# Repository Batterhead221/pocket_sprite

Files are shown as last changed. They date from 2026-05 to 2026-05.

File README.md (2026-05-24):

# POCKET_SPRITE

<p align="center">
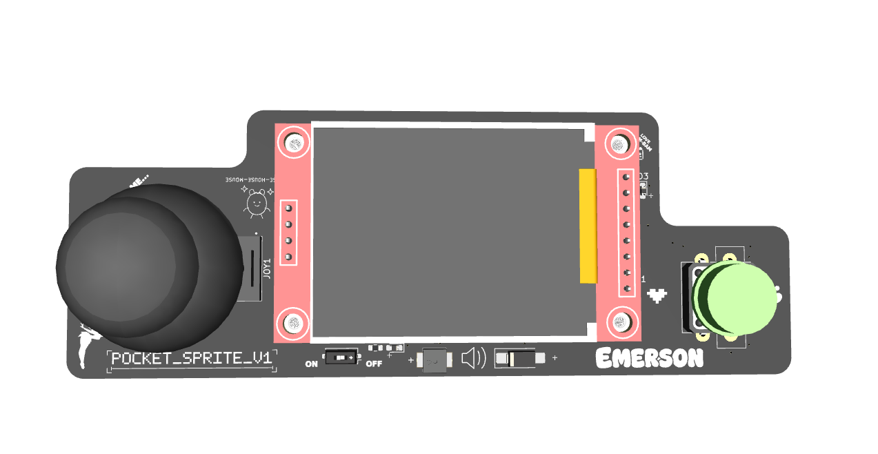
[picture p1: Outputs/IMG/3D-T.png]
POCKET_SPRITE top 3D board render
  
</p>

<p align="center">
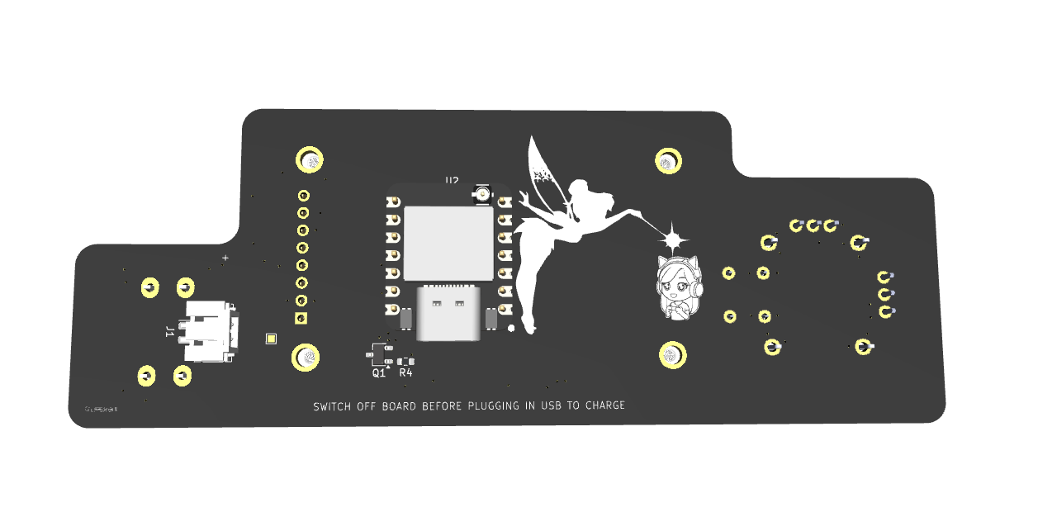
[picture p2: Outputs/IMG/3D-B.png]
POCKET_SPRITE bottom 3D board render
  
</p>

A custom ESP32-S3 handheld game console with joystick input, an action button, ST7735 color TFT display, buzzer audio, battery power, custom PCB artwork, and multiple built-in mini games.

POCKET_SPRITE is a compact original hardware project built around the Seeed Studio XIAO ESP32-S3 and a 1.8-inch ST7735 SPI TFT display. The board combines custom electronics, embedded firmware, pixel graphics, playful silkscreen art, and portable battery-powered hardware into a small handheld game device.

## Project Status

In progress. Breadboard input/display testing completed before the PCB version. Current hardware direction uses the XIAO ESP32-S3, joystick, 1.8-inch SPI TFT, A button, TFT backlight control, buzzer output, battery input through the XIAO BAT pads, and a switched 3.3V rail for game hardware.

## Features

- Seeed Studio XIAO ESP32-S3
- 1.8-inch ST7735 SPI TFT display
- Joystick input
- One action button
- TFT backlight control
- Buzzer output
- Battery input through the XIAO battery pads
- Switched 3.3V rail for game hardware
- Custom PCB outline
- Custom silkscreen artwork
- LovyanGFX display driver
- Multiple built-in games and modes

## Games / Modes

Current firmware includes:

- **Adventure**: small character-based adventure game
- **Pocket Pet**: virtual pet room with movement, jumping, ball pushing, and ball kicking
- **Dress Up**: character creator with selectable gender, hairstyles, colors, outfits, shoes, and a small playable character
- **BM Tron**: light-cycle style trail game
- **Snake**: classic snake mini game

## Hardware

| Function | Part / Notes |
|---|---|
| MCU | Seeed Studio XIAO ESP32-S3 |
| Display | 1.8-inch ST7735 SPI TFT |
| Display driver | LovyanGFX |
| Input | Joystick + one A button |
| Audio | Buzzer driven from GPIO |
| Power | Battery connected to XIAO BAT pads |
| Switched rail | XIAO_3V3 → switch → +3V3_SW |
| Board role | Portable handheld game/demo board |

## Pin Map

| XIAO Pin | Net | Function |
|---|---|---|
| D0 | JOY_SW | Joystick press |
| D1 | JOY_X | Joystick X analog |
| D2 | JOY_Y | Joystick Y analog |
| D3 | A_JUMP | A / jump button |
| D4 | CS | TFT chip select |
| D5 | DC | TFT data/command |
| D6 | RST | TFT reset |
| D7 | B-LITE | TFT backlight |
| D8 | SCK | TFT SPI clock |
| D9 | CHIRP | Buzzer drive |
| D10 | MOSI | TFT SPI MOSI |
| 3V3 | XIAO_3V3 | Regulated 3.3V from XIAO |
| GND | GND | Ground |
| BAT+ | XIAO_BAT+ | Battery positive |
| BAT- | XIAO_BAT- | Battery negative |

## Joystick Calibration

Breadboard joystick values measured during testing:

| Axis / Direction | Value / Behavior |
|---|---|
| X center | about 1970 |
| Y center | about 2020 |
| Deadzone | about 450 |
| UP | X low |
| DOWN | X high |
| LEFT | Y high |
| RIGHT | Y low |

Firmware should use calibration/deadzone handling instead of assuming perfect center values.

## Display Interface

The display is a 1.8-inch ST7735 SPI TFT.

```text
TFT CS    → D4
TFT DC    → D5
TFT RESET → D6
TFT BL    → D7 / B-LITE
TFT SCK   → D8
TFT MOSI  → D10
```

## Controls

```text
Joystick SW → D0
Joystick X  → D1
Joystick Y  → D2
A button    → D3
```

The joystick direction mapping from breadboard testing:

```text
UP    → X low
DOWN  → X high
LEFT  → Y high
RIGHT → Y low
```

## Audio Output

The buzzer output is labeled `CHIRP` and is driven from D9.

```text
D9 / CHIRP → buzzer drive
```

If the buzzer current is above the safe GPIO drive range, use a transistor or MOSFET driver instead of driving the buzzer directly from the XIAO GPIO.

## Power Design

The battery connects directly to the XIAO battery pads. The XIAO provides the regulated 3.3V rail used by the game hardware.

```text
Battery → XIAO BAT pads
XIAO_3V3 → switch → +3V3_SW
+3V3_SW → joystick / display / buzzer support hardware
```

Battery support should follow the Seeed Studio XIAO ESP32-S3 battery/BAT pad guidance for a 1S LiPo setup.

## Firmware Direction

Useful firmware modules:

- Joystick calibration
- Direction/deadzone handling
- A button input
- LovyanGFX display setup
- ST7735 display drawing helpers
- Sprite drawing and animation loop
- Game state/menu system
- Buzzer tone/beep helper
- Backlight control
- Battery-aware sleep or low-power behavior later

## Bring-Up Checklist

1. Confirm XIAO ESP32-S3 orientation and soldering.
2. Verify XIAO_3V3 and +3V3_SW behavior.
3. Test joystick X/Y ADC values.
4. Test joystick switch.
5. Test A button.
6. Test TFT display init over SPI.
7. Test TFT CS/DC/RESET behavior.
8. Test TFT backlight control on B-LITE.
9. Test buzzer output on CHIRP.
10. Run joystick-controlled movement demo.
11. Run each game mode.
12. Add battery testing only after USB-powered bring-up is stable.

## Design Notes

- Keep TFT SPI traces clean and reasonably short.
- Keep joystick analog lines away from buzzer switching where practical.
- Leave room for finger access around the joystick and A button.
- Keep silkscreen labels readable around controls.
- Treat joystick calibration as firmware data, not fixed ideal values.
- Keep the board small enough to feel handheld, not like a dinner plate with pixels.

## Repository Output Images

Expected image paths for GitHub README rendering:

```text
Outputs/
  IMG/
    3D-T.png
    3D-B.png
    SCHEMATIC.png
    L1-SIG.png
    L2-GND.png
```

## Safety / Design Note

POCKET_SPRITE is a low-voltage handheld electronics project. Verify battery polarity, switched power behavior, buzzer drive current, and display wiring before portable use.

Designed & Engineered by Brandon Shelly

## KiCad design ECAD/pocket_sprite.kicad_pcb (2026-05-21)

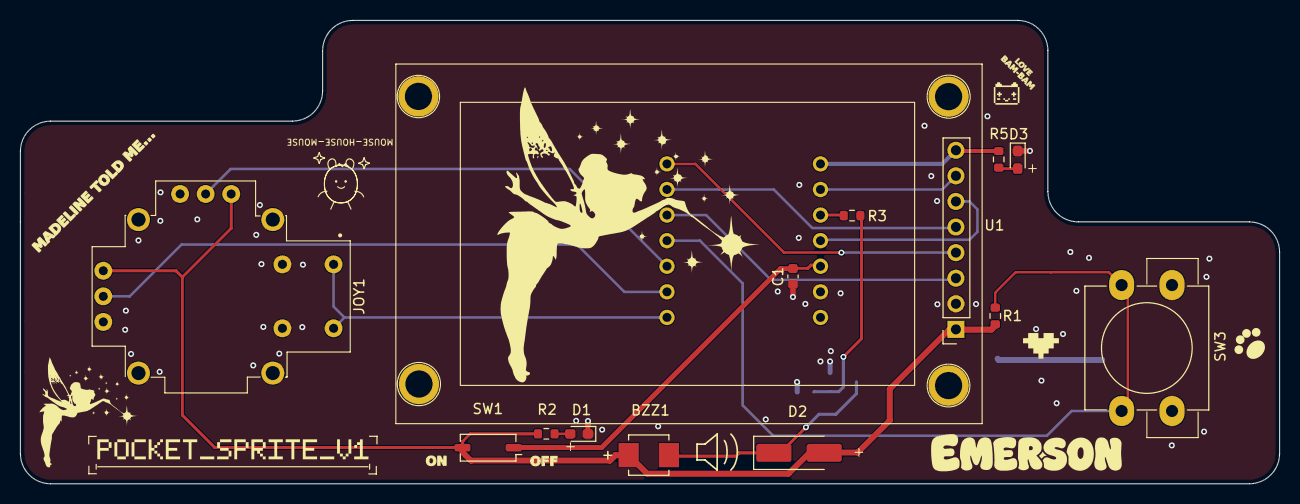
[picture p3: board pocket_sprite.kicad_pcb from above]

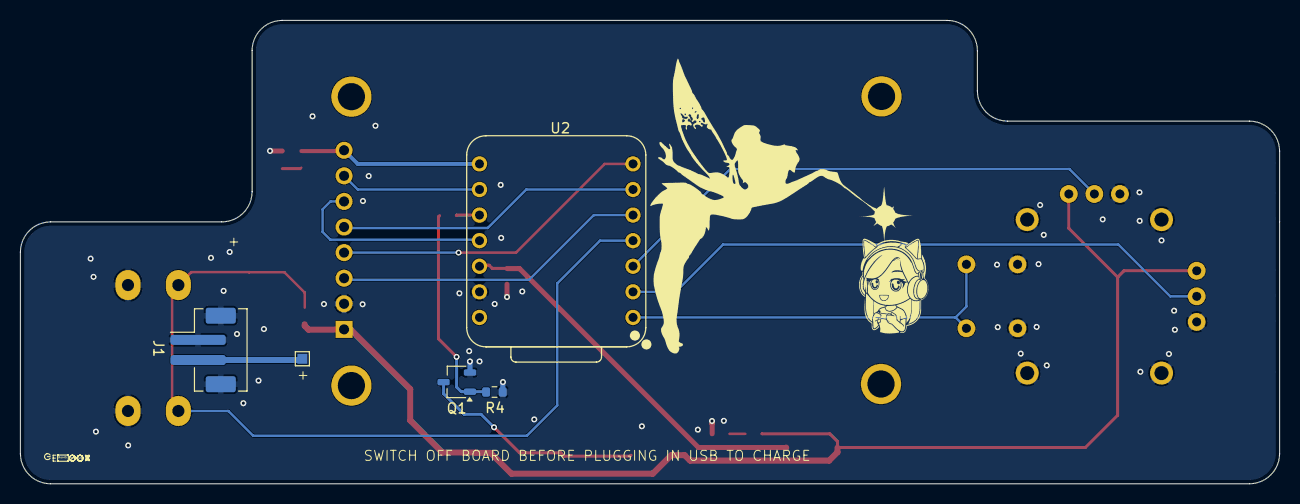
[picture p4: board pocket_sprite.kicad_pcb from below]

Board: 2 copper layers, 125.0 x 46.0 mm, 18 parts (5 on the bottom side), 19 nets.

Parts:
BZZ1: CMT-4023S-SMT-TR; CUI_CMT-4023S-SMT-TR
C1: 100nF; C_0603_1608Metric
D1, D3: LED_0603; D_0603_1608Metric_Pad1.05x0.95mm_HandSolder
D2: D_Schottky; D_SMA_Handsoldering
J1: Screw_Terminal_01x02; JST_PH_B2B-PH-SM4-TB_1x02-1MP_P2.00mm_Vertical
JOY1: JOYSTICK; XDCR_COM-09032_MODED
PAD1: BAT_PAD; TestPoint_Pad_1.0x1.0mm
Q1: AO3400A; TSOT-23
R1: 10K; R_0603_1608Metric
R2, R3, R5: 1K; R_0603_1608Metric
R4: 100K; R_0603_1608Metric
SW1: DS04-254-2-01BK-SMT; SW_DIP_SPSTx01_Slide_Copal_CHS-01A_W5.08mm_P1.27mm_JPin
SW3: BUTTON; Push_Button_W12mm
U1: 1.8_TFT_LCD_Display_Module; SPI_DISPLAY
U2: ESP32-S3; XIAO-ESP32_THROUGH_HOLE_PINS

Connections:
+3V3_SW: BZZ1.P, D2.2 (A), JOY1.H1 (H+), JOY1.V1 (V+), R1.2, R2.1, SW1.2 (N.O.), U1.1 (VCC)
A_JUMP: R1.1, SW3.1, U2.4 (D3)
B-LITE: R5.2, U1.8 (LED), U2.8 (RX_D7)
CHIRP: R3.2, U2.10 (D9)
CS: U1.3 (CS), U2.5 (D4)
DC: U1.5 (A0), U2.6 (D5)
GND: C1.2, D1.1 (K), D3.1 (K), J1.1, J1.3 (MP), J1.4 (MP), JOY1.B2A (SW-), JOY1.B2B (SW-), JOY1.H3 (H-), JOY1.S1 (SHIELD), JOY1.S2 (SHIELD__1), JOY1.S3 (SHIELD__2), JOY1.S4 (SHIELD__3), JOY1.V3 (V-), Q1.2 (S), R4.2, SW3.2, U1.2 (GND), U2.13 (GND)
JOY_SW: JOY1.B1A (SW+), JOY1.B1B (SW+), U2.1 (D0)
JOY_X: JOY1.H2 (H), U2.2 (D1)
JOY_Y: JOY1.V2 (V), U2.3 (D2)
MOSI: U1.6 (SDA), U2.11 (D10)
unnamed: D1.2 (A), R2.2
unnamed: BZZ1.N, D2.1 (K), Q1.3 (D)
unnamed: D3.2 (A), R5.1
unnamed: Q1.1 (G), R3.1, R4.1
RST: U1.4 (RESET), U2.7 (TX_D6)
SCK: U1.7 (SCK), U2.9 (D8)
XIAO_3V3: C1.1, SW1.1 (COM), U2.12 (VCC_3V3)
XIAO_BAT+: J1.2, PAD1.1 (1_1)

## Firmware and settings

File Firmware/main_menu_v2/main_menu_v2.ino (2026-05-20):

#include <LovyanGFX.hpp>
#include <SPI.h>

// ======================================================
// POCKET_SPRITE - ARCADE SHELL v2.0 MAIN MENU + ADVENTURE TITLE
// XIAO ESP32-S3 + ST7735 TFT + Joystick + A Button
//
// v1.6 LOVYANGFX PASS:
// - Switches display driver from Adafruit_ST7735 to LovyanGFX
// - Pre-renders common top-down character sprites into ESP32-S3 SRAM sprites
// - Keeps gameplay/state flow from the working V4 sketch
// - Adds main menu shell
// - Adventure starts from menu
// - Pocket Pet placeholder
// - Dress Up placeholder
// - Existing adventure preserved:
//   Level 1: Old School platformer, find blue hat
//   Level 2: Garden maze, find friend
//   Level 3: Bridge crossing, cross together
//
// Confirmed:
// TFT driver: LovyanGFX Panel_ST7735S
// TFT rotation: setRotation(3)
// Color order: rgb_order=true
// ======================================================


// -------------------- PIN MAP --------------------
#define JOY_SW_PIN   D0
#define JOY_X_PIN    D1
#define JOY_Y_PIN    D2
#define A_BUTTON_PIN D3

#define TFT_CS       D4
#define TFT_DC       D5
#define TFT_RST      D6
#define TFT_BL       D7
#define TFT_SCLK     D8
#define TFT_MOSI     D10


// -------------------- COLORS --------------------
#define C_BLACK       0x0000
#define C_WHITE       0xFFFF
#define C_BLUE        0x001F
#define C_SKY         0x5D9F
#define C_GREEN       0x07E0
#define C_DARK_GREEN  0x03E0
#define C_YELLOW      0xFFE0
#define C_MAGENTA     0xF81F
#define C_CYAN        0x07FF
#define C_RED         0xF800
#define C_ORANGE      0xFD20
#define C_TAN         0xD5B1
#define C_BROWN       0x8200
#define C_PINK        0xF81F
#define C_GRAY        0x8410
#define C_DARK_GRAY   0x4208
#define C_DARK_BLUE   0x0010
#define C_DOOR        0x5A20
#define C_GOLD        0xFEA0
#define C_SKIN        0xFDB8
#define C_GRASS       0x05E0
#define C_PATH        0xD69A
#define C_FLOWER      0xF81F
#define C_WATER       0x04FF
#define C_LEAF        0x07E0
#define C_BRIDGE      0xA145


// -------------------- DISPLAY --------------------
// LovyanGFX is faster than Adafruit_GFX on ESP32-S3 and lets us
// keep the display config inside this sketch instead of editing a
// library User_Setup file.
class LGFX : public lgfx::LGFX_Device {
  lgfx::Panel_ST7735S _panel_instance;
  lgfx::Bus_SPI _bus_instance;

public:
  LGFX(void) {
    {
      auto cfg = _bus_instance.config();
      cfg.spi_host = SPI2_HOST;
      cfg.spi_mode = 0;
      cfg.freq_write = 27000000;      // Confirmed stable on POCKET_SPRITE ST7735S test.
      cfg.freq_read = 16000000;
      cfg.spi_3wire = false;
      cfg.use_lock = true;
      cfg.dma_channel = SPI_DMA_CH_AUTO;
      cfg.pin_sclk = TFT_SCLK;
      cfg.pin_mosi = TFT_MOSI;
      cfg.pin_miso = -1;
      cfg.pin_dc = TFT_DC;
      _bus_instance.config(cfg);
      _panel_instance.setBus(&_bus_instance);
    }

    {
      auto cfg = _panel_instance.config();
      cfg.pin_cs = TFT_CS;
      cfg.pin_rst = TFT_RST;
      cfg.pin_busy = -1;

      cfg.panel_width = 128;
      cfg.panel_height = 160;
      cfg.memory_width = 128;
      cfg.memory_height = 160;
      cfg.offset_x = 0;
      cfg.offset_y = 0;
      cfg.offset_rotation = 0;
      cfg.dummy_read_pixel = 8;
      cfg.dummy_read_bits = 1;
      cfg.readable = false;
      cfg.invert = false;
      cfg.rgb_order = true;
      cfg.dlen_16bit = false;
      cfg.bus_shared = false;
      _panel_instance.config(cfg);
    }

    setPanel(&_panel_instance);
  }
};

LGFX tft;

// Transparent key used only for SRAM sprite blits. Avoid 0x0000 because
// the game uses true black in the art.
#define C_TRANSPARENT_KEY 0x0001

LGFX_Sprite sprMadelynA(&tft);
LGFX_Sprite sprMadelynB(&tft);
LGFX_Sprite sprFriendA(&tft);
LGFX_Sprite sprFriendB(&tft);

// Pocket Pet sprites are also pre-rendered into ESP32-S3 SRAM.
// This keeps pet animation smoother under LovyanGFX.
LGFX_Sprite sprPetIdle(&tft);
LGFX_Sprite sprPetWalkA(&tft);
LGFX_Sprite sprPetWalkB(&tft);
bool commonSpritesReady = false;
bool petSpritesReady = false;


// ======================================================
// APP STATE
// ======================================================

enum AppState {
  BOOT,
  TITLE,
  MAIN_MENU,
  SCHOOL_ROOM,
  GARDEN_INTRO,
  GARDEN_MAZE,
  FRIEND_FOUND,
  BRIDGE_INTRO,
  BRIDGE_CROSSING,
  BRIDGE_CLEAR,
  CITY_INTRO,
  CITY_WALK,
  CITY_CLEAR,
  POCKET_PET,
  DRESS_UP,
  DRESS_PLAY,
  TRON_GAME,
  SNAKE_GAME
};

AppState appState = BOOT;

// ======================================================
// JOYSTICK / BUTTON STATE
// ======================================================

const int JOY_X_CENTER = 1970;
const int JOY_Y_CENTER = 2020;
const int JOY_DEADZONE = 450;

int joyX = 0;
int joyY = 0;

bool joyPressed = false;
bool aPressed = false;
bool lastJoyPressed = false;
bool lastAPressed = false;

String direction = "CENTER";
String lastDirection = "CENTER";

// ======================================================
// MENU / LEVEL 1 PLAYER STATE RESTORE
// ======================================================

const int MENU_COUNT = 5;
int menuIndex = 0;

float girlX = 12;
float girlY = 96;
float oldGirlX = 12;
float oldGirlY = 96;

float girlVX = 0;
float girlVY = 0;

const int girlW = 16;
const int girlH = 19;

const float groundMoveSpeed = 3.2;
const float airMoveSpeed = 2.35;
const float gravity = 2.4;
const float jumpVelocity = -13.2;
const float maxFallSpeed = 15.0;

bool onGround = false;
bool facingRight = true;
bool jumpHeld = false;

bool hatCollected = false;
bool oldHatCollected = false;

const int hatX = 96;
const int hatY = 62;
const int hatW = 13;
const int hatH = 8;

const int doorX = 138;
const int doorY = 82;
const int doorW = 16;
const int doorH = 36;

inline int girlDrawX() { return (int)girlX - 1; }
inline int girlDrawY() { return (int)girlY; }



// ======================================================
// FUNCTION PROTOTYPES
// Arduino sometimes fails to auto-prototype larger sketches.
// ======================================================

bool rectsOverlap(int ax, int ay, int aw, int ah,
                  int bx, int by, int bw, int bh);

void redrawSchoolPatch(int x, int y, int w, int h);

void drawBridgeFrame();
void drawBridgeClearScreen();
void drawBridgePair();
void drawBridgeMadelyn(int x, int y);
void drawBridgeFriend(int x, int y);
void drawBridgeLeaves();
void updateBridgeClear();
void drawCityIntro();
void updateCityIntro();
void startCityWalk();
void updateCityWalk();
void updateCityMovement();
bool cityHitsWall(int x, int y);
void checkCityGoal();
void drawCityScene();
void drawCityStatic();
void drawCityFrame();
void redrawCityPatch(int x, int y, int w, int h);
void drawCityPair();
void drawCityMadelyn(int x, int y);
void drawCityFriend(int x, int y);
void drawWrigleyDog(int x, int y);
void drawCityClearScreen();
void updateCityClear();
void startPocketPet();
void drawPocketPetRoom();
void updatePocketPet();
void updatePocketPetAButton();
void updatePocketPetPhysics();
void drawPocketPetFrame();
void redrawPocketPetPatch(int x, int y, int w, int h);
void drawPocketPetCreature(int x, int y);
void drawPocketPetToy();
void updatePocketPetBall();
void checkPocketPetBallInteractions();
void kickPocketPetBall();
void drawPocketPetBall();
void buildPetSprites();
void drawPetShadow(int x, int y);
void startDressUp();
void drawDressUpScreen();
void updateDressUp();
void nextDressStep();
void cycleDressValue(int delta);
void drawDressFacePreview(int x, int y);
void drawDressFullPreview(int x, int y, int scaleMode);
void drawDressGirlFace(int x, int y, bool closeMode);
void drawDressBoyFace(int x, int y, bool closeMode);
void drawDressGirlBody(int x, int y, bool closeMode);
void drawDressBoyBody(int x, int y, bool closeMode);
void drawGirlHair(int x, int y, uint16_t hairColor, bool closeMode);
void drawBoyHair(int x, int y, uint16_t hairColor, bool closeMode);
void drawBoyFacialHair(int x, int y, uint16_t hairColor, bool closeMode);
uint16_t getDressHairColor(int index);
uint16_t getDressOutfitColor(int index);
uint16_t getDressShoeColor(int index);
const char* getDressStepName();
const char* getDressValueName();
const char* getGirlHairName(int index);
const char* getBoyHairName(int index);
const char* getHairColorNameNew(int index);
const char* getGirlOutfitName(int index);
const char* getBoyOutfitName(int index);
const char* getOutfitColorNameNew(int index);
const char* getShoeColorName(int index);
const char* getBoyBeardName(int index);
const char* getBoyMustacheName(int index);
void startDressPlay();
void updateDressPlay();
void updateDressPlayPhysics();
void drawDressPlayScene();
void drawDressPlayFrame();
void redrawDressPlayPatch(int x, int y, int w, int h);
void drawDressPlayCharacter(int x, int y);
void startTronGame();
void updateTronGame();
void drawTronScene();
void drawTronHUD();
void resetTronRound();
void updateTronDirection();
void drawTronCell(int gx, int gy, uint16_t color);
bool tronCellBlocked(int gx, int gy);

void startSnakeGame();
void updateSnakeGame();
void drawSnakeScene();
void drawSnakeHUD();
void resetSnakeRound();
void updateSnakeDirection();
void drawSnakeCell(int gx, int gy, uint16_t color);
bool snakeHitsBody(int gx, int gy);
void placeSnakeFood();
;

// ======================================================
// SCREEN / ROOM CONSTANTS
// ======================================================

const int HEADER_H = 18;
const int GROUND_Y = 118;

struct Platform {
  int x;
  int y;
  int w;
  int h;
};

const int PLATFORM_COUNT = 3;
Platform platforms[PLATFORM_COUNT] = {
  {16, 92, 50, 6},
  {76, 72, 52, 6},
  {28, 54, 38, 6}
};

void drawSinglePlatform(Platform p);


// ======================================================
// RECT / OBSTACLE HELPERS
// ======================================================

struct Rect {
  int x;
  int y;
  int w;
  int h;
};


// ======================================================
// LEVEL 2 TOP-DOWN GARDEN STATE
// ======================================================

const int GARDEN_OBSTACLE_COUNT = 10;

Rect gardenWalls[GARDEN_OBSTACLE_COUNT] = {
  {0,   HEADER_H, 160, 5},
  {0,   123,      160, 5},
  {0,   HEADER_H, 5,   110},
  {155, HEADER_H, 5,   110},

  {18,  38,       62,  9},
  {98,  38,       42,  9},

  {18,  70,       38,  9},
  {76,  70,       64,  9},

  {38,  98,       62,  9},
  {118, 90,       9,   28}
};

int gardenX = 12;
int gardenY = 108;
int oldGardenX = 12;
int oldGardenY = 108;

const int gardenW = 10;
const int gardenH = 12;
const int gardenSpeed = 3;

const int friendX = 136;
const int friendY = 28;
const int friendW = 11;
const int friendH = 13;


// ======================================================
// LEVEL 3 BRIDGE STATE
// ======================================================

int bridgeX = 8;
int bridgeY = 72;
int oldBridgeX = 8;
int oldBridgeY = 72;

const int bridgeW = 10;
const int bridgeH = 12;
const int bridgeSpeed = 3;

const int bridgeGoalX = 145;
const int bridgeGoalY = 62;
const int bridgeGoalW = 10;
const int bridgeGoalH = 28;

const int BRIDGE_OBSTACLE_COUNT = 6;

Rect bridgeObstacles[BRIDGE_OBSTACLE_COUNT] = {
  {34,  60,  16, 10},
  {62,  90,  18, 10},
  {94,  54,  16, 10},
  {110, 82,  20, 10},
  {52,  74,  10, 8},
  {86,  76,  10, 8}
};

int windCounter = 0;
int windPush = 0;

// ======================================================
// LEVEL 4 CITY STATE
// ======================================================

int cityX = 10;
int cityY = 92;
int oldCityX = 10;
int oldCityY = 92;

const int cityW = 10;
const int cityH = 12;
const int citySpeed = 4;

const int cityGoalX = 132;
const int cityGoalY = 72;
const int cityGoalW = 18;
const int cityGoalH = 22;

const int CITY_OBSTACLE_COUNT = 7;

Rect cityObstacles[CITY_OBSTACLE_COUNT] = {
  {0,   HEADER_H, 160, 5},
  {0,   123,      160, 5},
  {0,   HEADER_H, 5,   110},
  {155, HEADER_H, 5,   110},

  {30,  39,       34,  26},
  {78,  86,       22,  18},
  {112, 38,       12,  30}
};

// ======================================================
// POCKET PET STATE
// ======================================================

int petX = 72;
int petY = 92;
int oldPetX = 72;
int oldPetY = 92;

float petVY = 0;
bool petOnGround = false;
bool petJumpHeld = false;
bool petKickHeld = false;

const int petW = 26;
const int petH = 22;
const int PET_GROUND_Y = 112;

const int petMoveSpeed = 4;
const float petGravity = 0.55;
const float petJumpVelocity = -11.2;
const float petMaxFall = 5.5;

bool petFacingRight = true;
int petAnim = 0;

// Pocket Pet controls:
// joystick UP = jump
// A button = kick ball
// joystick press = back to menu
// v2.3.1: robust A/UP controls
unsigned long petAPressStart = 0;
bool petAHoldKickDone = false;
const unsigned long PET_KICK_HOLD_MS = 520; // unused now, kept harmless for rollback

// Pocket Pet ball physics
float petBallX = 118;
float petBallY = 104;
float oldPetBallX = 118;
float oldPetBallY = 104;
float petBallVX = 0;
float petBallVY = 0;
const int petBallR = 7;


// ======================================================
// DRESS UP STATE
// ======================================================

enum DressGender {
  DRESS_GIRL,
  DRESS_BOY
};

enum DressStep {
  STEP_GENDER,
  STEP_HAIR,
  STEP_BEARD,
  STEP_MUSTACHE,
  STEP_HAIR_COLOR,
  STEP_OUTFIT,
  STEP_OUTFIT_COLOR,
  STEP_SHOES,
  STEP_CONFIRM
};

DressGender dressGender = DRESS_GIRL;
DressStep dressStep = STEP_GENDER;

int girlHairStyle = 0;
int girlHairColor = 0;
int girlOutfitStyle = 0;
int girlOutfitColor = 0;
int girlShoes = 0;

int boyHairStyle = 0;
int boyHairColor = 0;
int boyBeard = 0;
int boyMustache = 0;
int boyOutfitStyle = 0;
int boyOutfitColor = 0;
int boyShoes = 0;

const int GIRL_HAIR_COUNT = 6;
const int BOY_HAIR_COUNT = 7;
const int HAIR_COLOR_COUNT = 5;
const int GIRL_OUTFIT_COUNT = 5;
const int BOY_OUTFIT_COUNT = 5;
const int OUTFIT_COLOR_COUNT = 6;
const int SHOE_COLOR_COUNT = 5;
const int BOY_BEARD_COUNT = 4;
const int BOY_MUSTACHE_COUNT = 5;

int dressPlayX = 72;
int dressPlayY = 92;
int oldDressPlayX = 72;
int oldDressPlayY = 92;
float dressPlayVY = 0;
bool dressPlayOnGround = false;
bool dressPlayJumpHeld = false;
bool dressPlayFacingRight = true;

const int dressPlayW = 24;
const int dressPlayH = 48;
const int DRESS_PLAY_GROUND_Y = 118;
const int dressPlaySpeed = 3;
const float dressPlayGravity = 1.0;
const float dressPlayJumpVelocity = -10.5;
const float dressPlayMaxFall = 7.0;


// ======================================================
// MINI GAME STATE: BM TRON + SNAKE
// ======================================================

const int MINI_CELL = 4;
const int MINI_GRID_W = 40;
const int MINI_GRID_H = 28;
const int MINI_TOP = 12;

bool tronTrail[MINI_GRID_W][MINI_GRID_H];
int tronX = 7;
int tronY = 14;
int tronDX = 1;
int tronDY = 0;
int tronScore = 0;
bool tronGameOver = false;
unsigned long tronLastStep = 0;
const unsigned long tronStepDelay = 72;

int snakeX[180];
int snakeY[180];
int snakeLen = 5;
int snakeDX = 1;
int snakeDY = 0;
int snakeFoodX = 20;
int snakeFoodY = 14;
int snakeScore = 0;
bool snakeGameOver = false;
unsigned long snakeLastStep = 0;
const unsigned long snakeStepDelay = 115;


// ======================================================
// TIMING
// ======================================================

unsigned long bootStartTime = 0;
unsigned long lastFrame = 0;
const unsigned long frameDelay = 28;


// ======================================================
// SETUP
// ======================================================

void setup() {
  Serial.begin(115200);
  delay(1000);

  pinMode(JOY_SW_PIN, INPUT_PULLUP);
  pinMode(A_BUTTON_PIN, INPUT_PULLUP);
  pinMode(TFT_BL, OUTPUT);
  digitalWrite(TFT_BL, HIGH);

  tft.init();
  tft.setRotation(3);
  // Backlight is controlled directly because this board already has BL on D7.
  digitalWrite(TFT_BL, HIGH);
  buildCommonSprites();

  bootStartTime = millis();
  drawBootScreen();
}


// ======================================================
// LOOP
// ======================================================

void loop() {
  readControls();

  if (appState == BOOT) {
    updateBoot();
  }
  else if (appState == TITLE) {
    updateTitle();
  }
  else if (appState == MAIN_MENU) {
    updateMainMenu();
  }
  else if (appState == SCHOOL_ROOM) {
    updateSchoolRoom();
  }
  else if (appState == GARDEN_INTRO) {
    updateGardenIntro();
  }
  else if (appState == GARDEN_MAZE) {
    updateGardenMaze();
  }
  else if (appState == FRIEND_FOUND) {
    updateFriendFound();
  }
  else if (appState == BRIDGE_INTRO) {
    updateBridgeIntro();
  }
  else if (appState == BRIDGE_CROSSING) {
    updateBridgeCrossing();
  }
  else if (appState == BRIDGE_CLEAR) {
  updateBridgeClear();
}
else if (appState == CITY_INTRO) {
  updateCityIntro();
}
else if (appState == CITY_WALK) {
  updateCityWalk();
}
else if (appState == CITY_CLEAR) {
  updateCityClear();
}
else if (appState == POCKET_PET) {
  updatePocketPet();
}
else if (appState == DRESS_UP) {
  updateDressUp();
}
else if (appState == DRESS_PLAY) {
  updateDressPlay();
}
else if (appState == TRON_GAME) {
  updateTronGame();
}
else if (appState == SNAKE_GAME) {
  updateSnakeGame();
}

  lastAPressed = aPressed;
  lastJoyPressed = joyPressed;
  lastDirection = direction;
}


// ======================================================
// INPUT
// ======================================================

void readControls() {
  joyX = analogRead(JOY_X_PIN);
  joyY = analogRead(JOY_Y_PIN);

  joyPressed = digitalRead(JOY_SW_PIN) == LOW;
  aPressed = digitalRead(A_BUTTON_PIN) == LOW;

  direction = "CENTER";

  // Confirmed POCKET_SPRITE mapping after screen rotation.
  if (joyX < JOY_X_CENTER - JOY_DEADZONE) {
    direction = "DOWN";
  }
  else if (joyX > JOY_X_CENTER + JOY_DEADZONE) {
    direction = "UP";
  }
  else if (joyY > JOY_Y_CENTER + JOY_DEADZONE) {
    direction = "RIGHT";
  }
  else if (joyY < JOY_Y_CENTER - JOY_DEADZONE) {
    direction = "LEFT";
  }
}

bool aJustPressed() {
  return aPressed && !lastAPressed;
}

bool joyJustPressed() {
  return joyPressed && !lastJoyPressed;
}

bool directionJustPressed(String target) {
  return direction == target && lastDirection != target;
}



// ======================================================
// PIXEL SPRITE HELPERS
// ======================================================

uint16_t spriteColor(char c) {
  if (c == 'K') return C_BLACK;
  if (c == 'W') return C_WHITE;
  if (c == 'B') return C_BLUE;
  if (c == 'C') return C_CYAN;
  if (c == 'D') return C_DARK_BLUE;
  if (c == 'R') return C_RED;
  if (c == 'O') return C_ORANGE;
  if (c == 'Y') return C_YELLOW;
  if (c == 'M') return C_MAGENTA;
  if (c == 'P') return C_PINK;
  if (c == 'S') return C_SKIN;
  if (c == 'N') return C_BROWN;
  if (c == 'G') return C_GREEN;
  if (c == 'g') return C_DARK_GREEN;
  return C_BLACK;
}

int spriteRowsWidth(const char* const rows[], int h) {
  int w = 0;
  for (int row = 0; row < h; row++) {
    int len = strlen(rows[row]);
    if (len > w) w = len;
  }
  return w;
}

void drawRowsToSprite(LGFX_Sprite& spr, const char* const rows[], int h) {
  int w = spriteRowsWidth(rows, h);
  spr.setColorDepth(16);
  spr.createSprite(w, h);
  spr.fillSprite(C_TRANSPARENT_KEY);

  for (int row = 0; row < h; row++) {
    const char* line = rows[row];
    for (int col = 0; line[col] != '\0'; col++) {
      char c = line[col];
      if (c != ' ') {
        spr.drawPixel(col, row, spriteColor(c));
      }
    }
  }
}

void drawSpriteRows(int x, int y, const char* const rows[], int h) {
  // Fallback/general-purpose pixel-map draw. We wrap in one SPI transaction
  // so occasional non-cached sprites still draw faster and cleaner.
  tft.startWrite();
  for (int row = 0; row < h; row++) {
    const char* line = rows[row];
    for (int col = 0; line[col] != '\0'; col++) {
      char c = line[col];
      if (c != ' ') {
        tft.drawPixel(x + col, y + row, spriteColor(c));
      }
    }
  }
  tft.endWrite();
}

void buildCommonSprites() {
  if (commonSpritesReady) return;

  static const char* const madelynA[] = {
    "  YYYY  ", " YYYYYY ", "YYYYYYYY", "RRSSSSRR",
    "RSKSSKSR", " RSSSSR ", "  RSSR  ", "  YYYY  ",
    " YYYYYY ", "YYYYYYYY", "  K  K  ", " KK  KK "
  };
  static const char* const madelynB[] = {
    "  YYYY  ", " YYYYYY ", "YYYYYYYY", "RRSSSSRR",
    "RSKSSKSR", " RSSSSR ", "  RSSR  ", "  YYYY  ",
    " YYYYYY ", "YYYYYYYY", " K    K ", "  KK KK "
  };
  static const char* const friendA[] = {
    " P  PP P ", "PPPPPPPP ", " NNSSNN  ", "NNSSSSNN ",
    "NSKSSKSN ", " NSSSSN  ", "  NSSN   ", "  BBBB   ",
    " BBBBBB  ", "BBBBBBBB ", "  K  K   ", " KK  KK  "
  };
  static const char* const friendB[] = {
    " P  PP P ", "PPPPPPPP ", " NNSSNN  ", "NNSSSSNN ",
    "NSKSSKSN ", " NSSSSN  ", "  NSSN   ", "  BBBB   ",
    " BBBBBB  ", "BBBBBBBB ", " K    K  ", "  KK KK  "
  };

  drawRowsToSprite(sprMadelynA, madelynA, 12);
  drawRowsToSprite(sprMadelynB, madelynB, 12);
  drawRowsToSprite(sprFriendA, friendA, 12);
  drawRowsToSprite(sprFriendB, friendB, 12);

  commonSpritesReady = true;
}

void drawTopDownMadelynSprite(int x, int y) {
  buildCommonSprites();
  bool step = ((millis() / 180) % 2) == 0;
  (step ? sprMadelynB : sprMadelynA).pushSprite(x, y, C_TRANSPARENT_KEY);
}

void drawTopDownFriendSprite(int x, int y) {
  buildCommonSprites();
  bool step = ((millis() / 180) % 2) == 0;
  (step ? sprFriendB : sprFriendA).pushSprite(x, y, C_TRANSPARENT_KEY);
}



// ======================================================
// BOOT / TITLE / MAIN MENU
// ======================================================

void drawBootScreen() {
  tft.fillScreen(C_BLACK);
  tft.setTextWrap(false);

  tft.setTextSize(2);
  tft.setTextColor(C_YELLOW);
  tft.setCursor(14, 28);
  tft.println("HI,");

  tft.setTextColor(C_CYAN);
  tft.setCursor(14, 54);
  tft.println("EMERSON!");

  tft.drawRect(0, 0, tft.width(), tft.height(), C_WHITE);
}
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
